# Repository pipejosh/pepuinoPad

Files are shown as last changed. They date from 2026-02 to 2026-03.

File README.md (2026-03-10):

# Pepuino Pad

This is the pepuino pad, a 9 by 9 midi launchpad, with per key rgb illumination (the brightness can only be set to 30% ish) the pepuino pad is a midi compatible launchpad to make music, this project, the shematics and the pcb are made in kicad, and the case and render are made in fusion 360 and it uses the custom made pepuino nano V1 as the main microcontroler (microcontroller based on a rp2040 chip)

###  Shematic
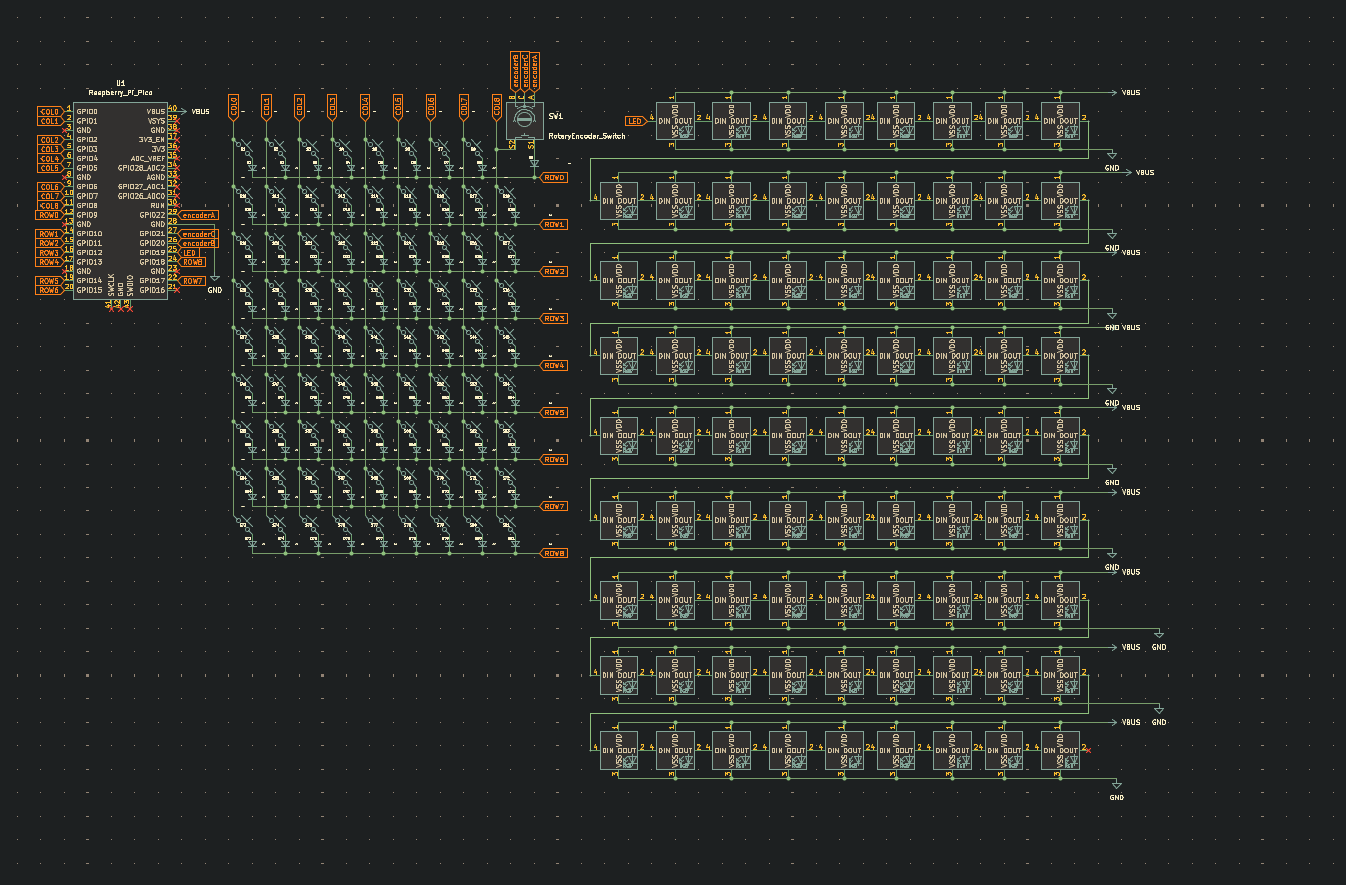
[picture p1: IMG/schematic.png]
schematic
 
### pcb
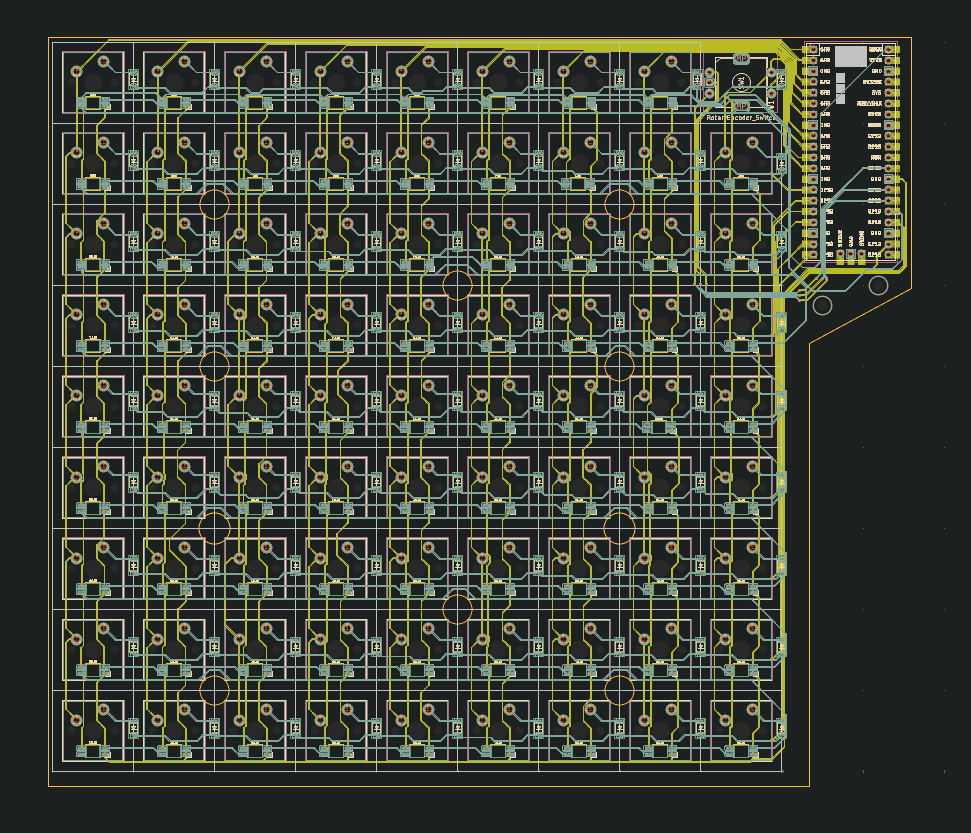
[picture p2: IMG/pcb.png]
pcb
 
### case
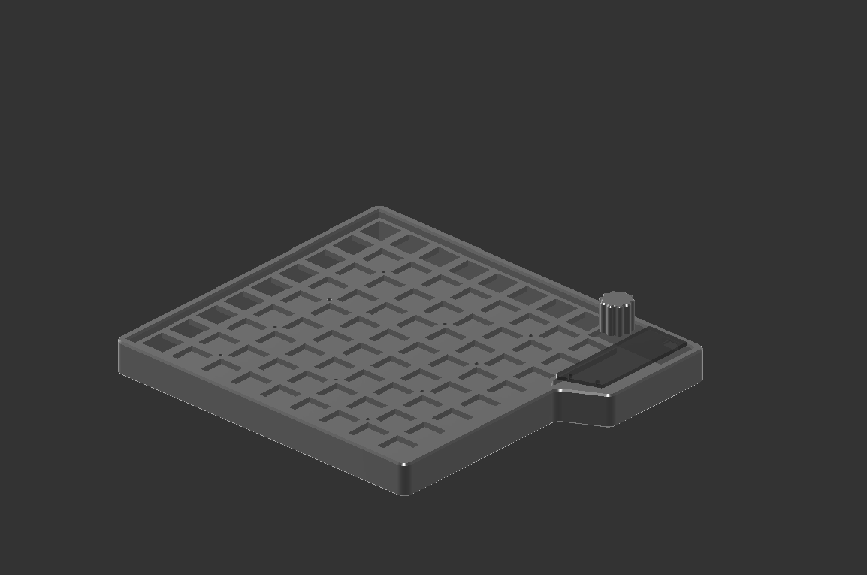
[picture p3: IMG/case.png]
case
 
### render
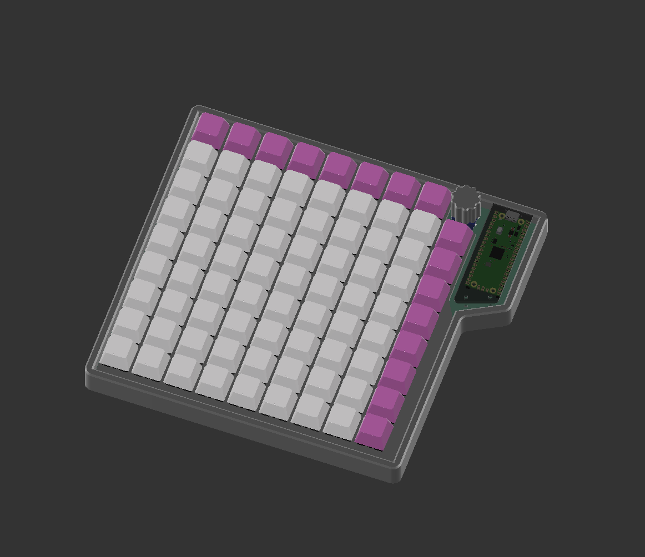
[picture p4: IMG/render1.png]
render1
 
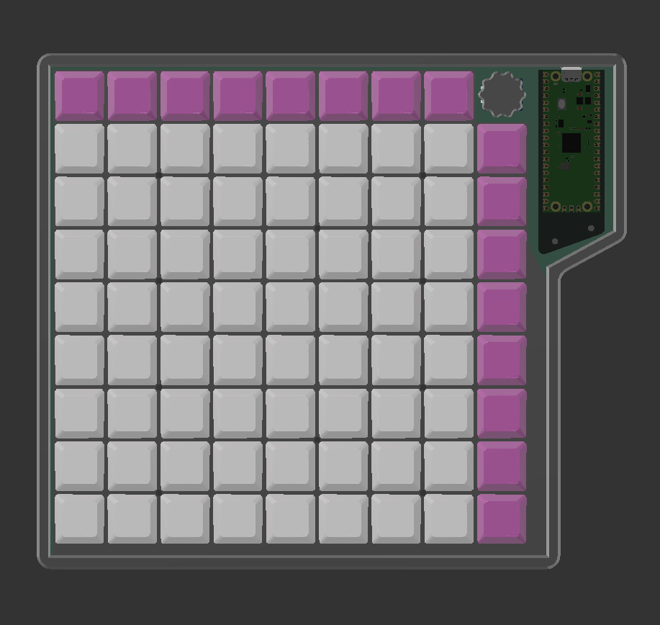
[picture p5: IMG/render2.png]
render2
  

## BOM
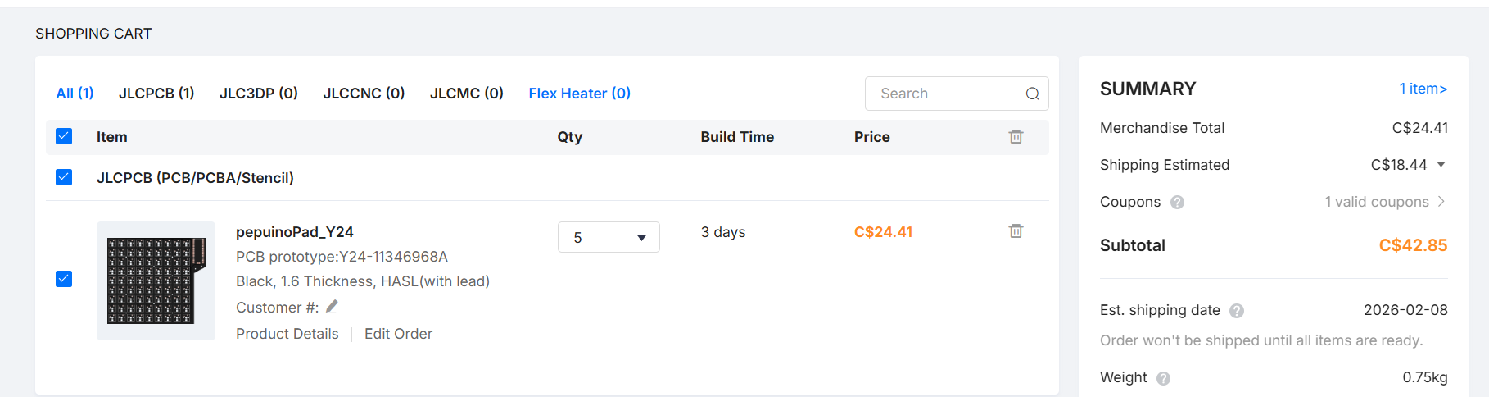
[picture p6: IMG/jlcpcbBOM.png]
BOM
 

## Components (KIT)

| Item | Description | Quantity | Unit Price | Total Price | URL |
|-----|---|---|---|---|-----|
| Blank keycaps | White | 90 | 0,13 | 11,81 | https://www.aliexpress.com/item/32842379355.html |
| Blank keycaps | Green | 20 | 0,19 | 3,77 | https://www.aliexpress.com/item/1005006116865547.html |
| Switches | Mechanical switches | 90 | 0,23 | 20,31 | https://www.aliexpress.com/item/1005009787231480.html |
| Diodes | SMD diodes | 100 | 0,03 | 3,08 | https://www.aliexpress.com/item/1005007160563285.html |
| M2 standoff | M2 standoff 5mm | 50 | 0,05 | 2,47 | https://www.aliexpress.com/item/1005006049595637.html |
| M2 screw | 5mm screw | 50 | 0,03 | 1,65 | https://www.aliexpress.com/item/1005005070119421.html |
| LED | SK6812 | 100 | 0,07 | 6,67 | https://www.aliexpress.com/item/1005005193716172.html |
| Roraty encoder | ec11 | 1 | 1,85 | 1,85 | https://www.aliexpress.com/item/1005007644083514.html |
| Taxes | AliExpress tax | — | — | 4,28 | — |

**Components Subtotal:** **55,89**

---

## PCB

| Item | Description | Price |
|-----|---|---|
| JLCPCB | Pepuino Pad PCB | 24,41 |
| JLCPCB Shipping | PCB shipping + taxes | 18,44 |

---

## Total

| Description | Amount |
|---|---|
| **Grand Total** | **98.74** |

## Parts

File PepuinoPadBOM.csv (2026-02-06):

KIT Items | Description | Quantity | Unit Price | Total Price | URL
blank keycaps | white | 90 | 0,13 | 11,81 | https://www.aliexpress.com/item/32842379355.html?spm=a2g0o.detail.0.0.60810ceR0ceRWl&mp=1
blank keycaps | green | 20 | 0,19 | 3,77 | https://www.aliexpress.com/item/1005006116865547.html?spm=a2g0o.detail.0.0.5325TAR5TAR5dv&mp=1
switches | mechanical switches | 90 | 0,23 | 20,31 | https://www.aliexpress.com/item/1005009787231480.html?spm=a2g0o.detail.0.0.67adNrIhNrIhyD&mp=1
diodes | smd diodes | 100 | 0,03 | 3,08 | https://www.aliexpress.com/item/1005007160563285.html?spm=a2g0o.detail.0.0.7fc4QlPlQlPlQO&mp=1
M2 standoff | M2 standoff 5mm | 50 | 0,05 | 2,47 | https://www.aliexpress.com/item/1005008504707668.html?spm=a2g0o.detail.0.0.5fe4VqYfVqYfAJ&mp=1
M2 screw | 5mm screw | 50 | 0,03 | 1,65 | https://www.aliexpress.com/item/1005005070119421.html
Led | sk6812 | 100 | 0,07 | 6,67 | https://www.aliexpress.com/item/1005005193716172.html?spm=a2g0o.cart.0.0.5b5d38daIIwypf&mp=1
raspberry pico | raspberry pico usb-c | 1 | 3,27 | 3,29 | https://www.aliexpress.com/item/1005006839247100.html?spm=a2g0o.cart.0.0.5b5d38daIIwypf&mp=1
taxes | aliexpress tax |  |  | 4,28
 |  |  | Components | 57,33
CASE Items | Description
JLCPCB | Pepuino Pad PCB | 21,84
JLCPCB Shipping | Shipping for PCB + taxes | 16,87
TOTAL | 96,04

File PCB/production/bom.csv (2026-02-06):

Designator | Footprint | Quantity | Value | LCSC Part #
D1, D10, D11, D12, D13, D14, D15, D16, D17, D18, D19, D2, D20, D21, D22, D23, D24, D25, D26, D27, D28, D29, D3, D30, D31, D32, D33, D34, D35, D36, D37, D38, D39, D4, D40, D41, D42, D43, D44, D45, D46, D47, D48, D49, D5, D50, D51, D52, D53, D54, D55, D56, D57, D58, D59, D6, D60, D61, D62, D63, D64, D65, D66, D67, D68, D69, D7, D70, D71, D72, D73, D74, D75, D76, D77, D78, D79, D8, D80, D81, D9 | Diode_SOD-123 | 81 | ~
D100, D101, D102, D103, D104, D105, D106, D107, D108, D109, D110, D111, D112, D113, D114, D115, D116, D117, D118, D119, D120, D121, D122, D123, D124, D125, D126, D127, D128, D129, D130, D131, D132, D133, D134, D135, D136, D137, D138, D139, D140, D141, D142, D143, D144, D145, D146, D147, D148, D149, D150, D151, D152, D153, D154, D155, D156, D157, D158, D159, D160, D161, D162, D82, D83, D84, D85, D86, D87, D88, D89, D90, D91, D92, D93, D94, D95, D96, D97, D98, D99 | LED_SK6812MINI | 81 | LED_SK6812MINI | C5149201
S1, S10, S11, S12, S13, S14, S15, S16, S17, S18, S19, S2, S20, S21, S22, S23, S24, S25, S26, S27, S28, S29, S3, S30, S31, S32, S33, S34, S35, S36, S37, S38, S39, S4, S40, S41, S42, S43, S44, S45, S46, S47, S48, S49, S5, S50, S51, S52, S53, S54, S55, S56, S57, S58, S59, S6, S60, S61, S62, S63, S64, S65, S66, S67, S68, S69, S7, S70, S71, S72, S73, S74, S75, S76, S77, S78, S79, S8, S80, S81, S9 | MX_PCB_1.00u | 81 | ~
U1 | Raspberry_Pi_Pico | 1 | Raspberry_Pi_Pico

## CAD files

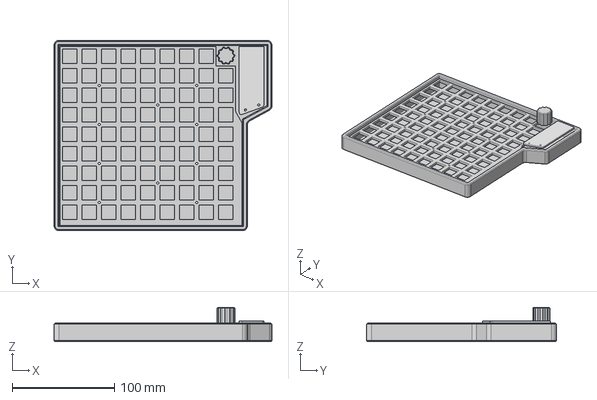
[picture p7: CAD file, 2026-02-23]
CAD/pepuinoPad_case.step
213.0 x 186.0 x 33.5 mm

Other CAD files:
CAD/pepuinoPad.f3z

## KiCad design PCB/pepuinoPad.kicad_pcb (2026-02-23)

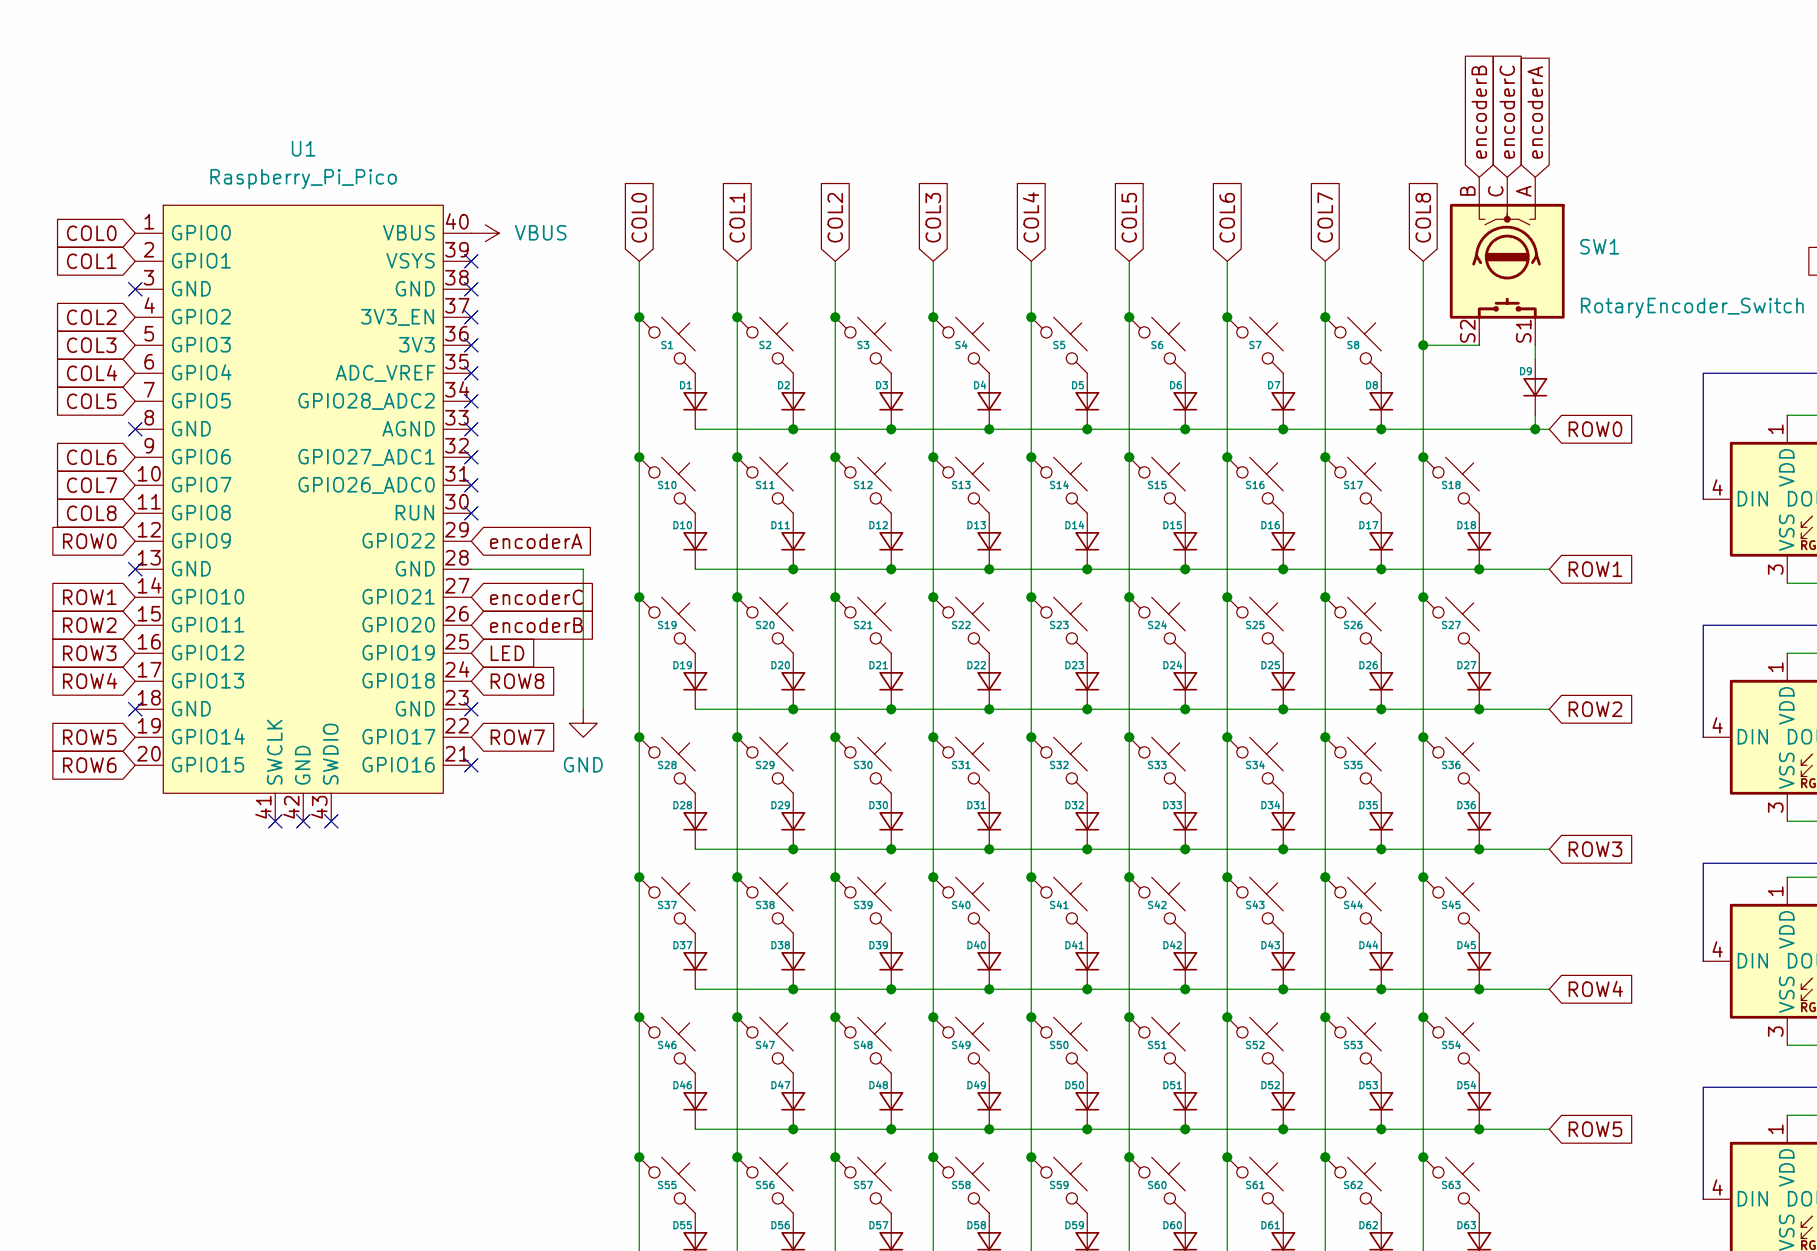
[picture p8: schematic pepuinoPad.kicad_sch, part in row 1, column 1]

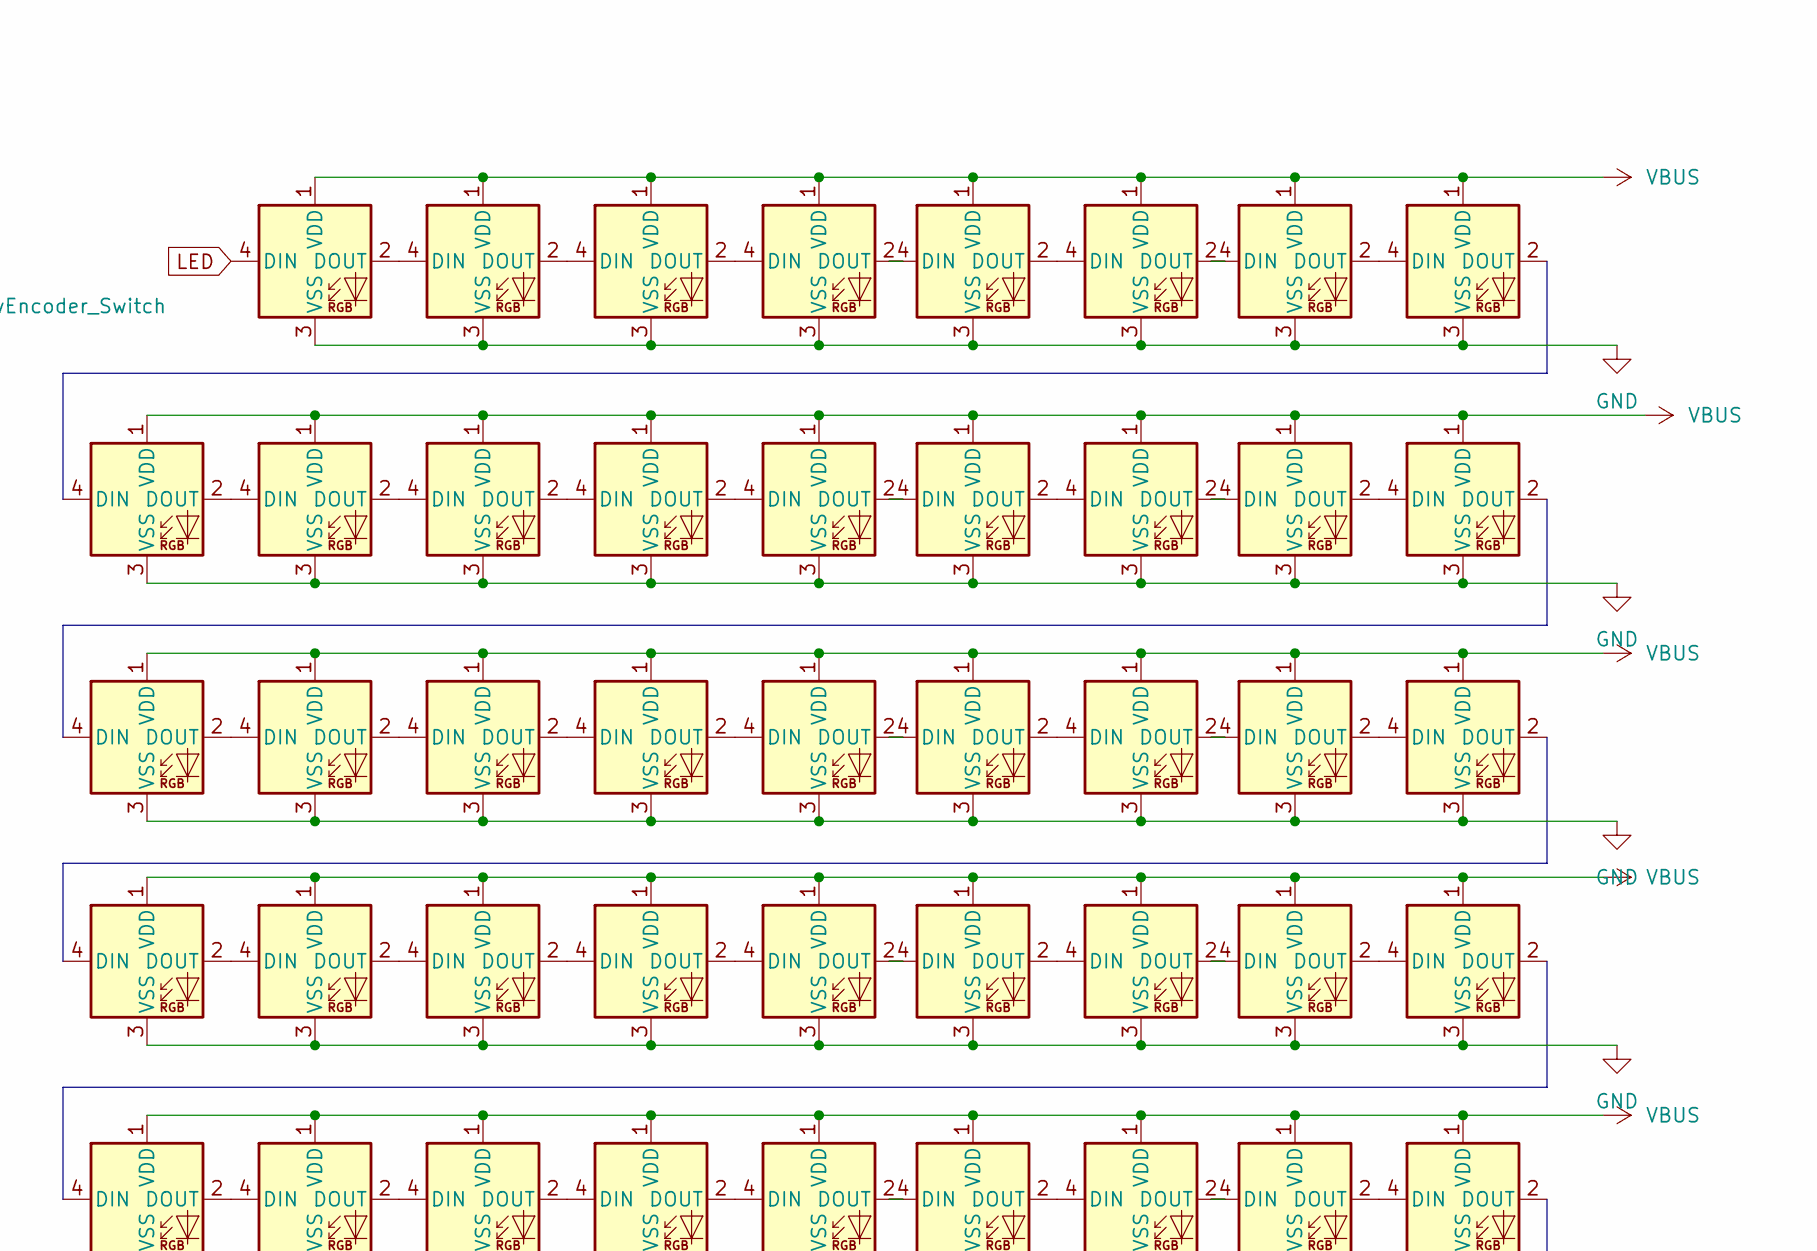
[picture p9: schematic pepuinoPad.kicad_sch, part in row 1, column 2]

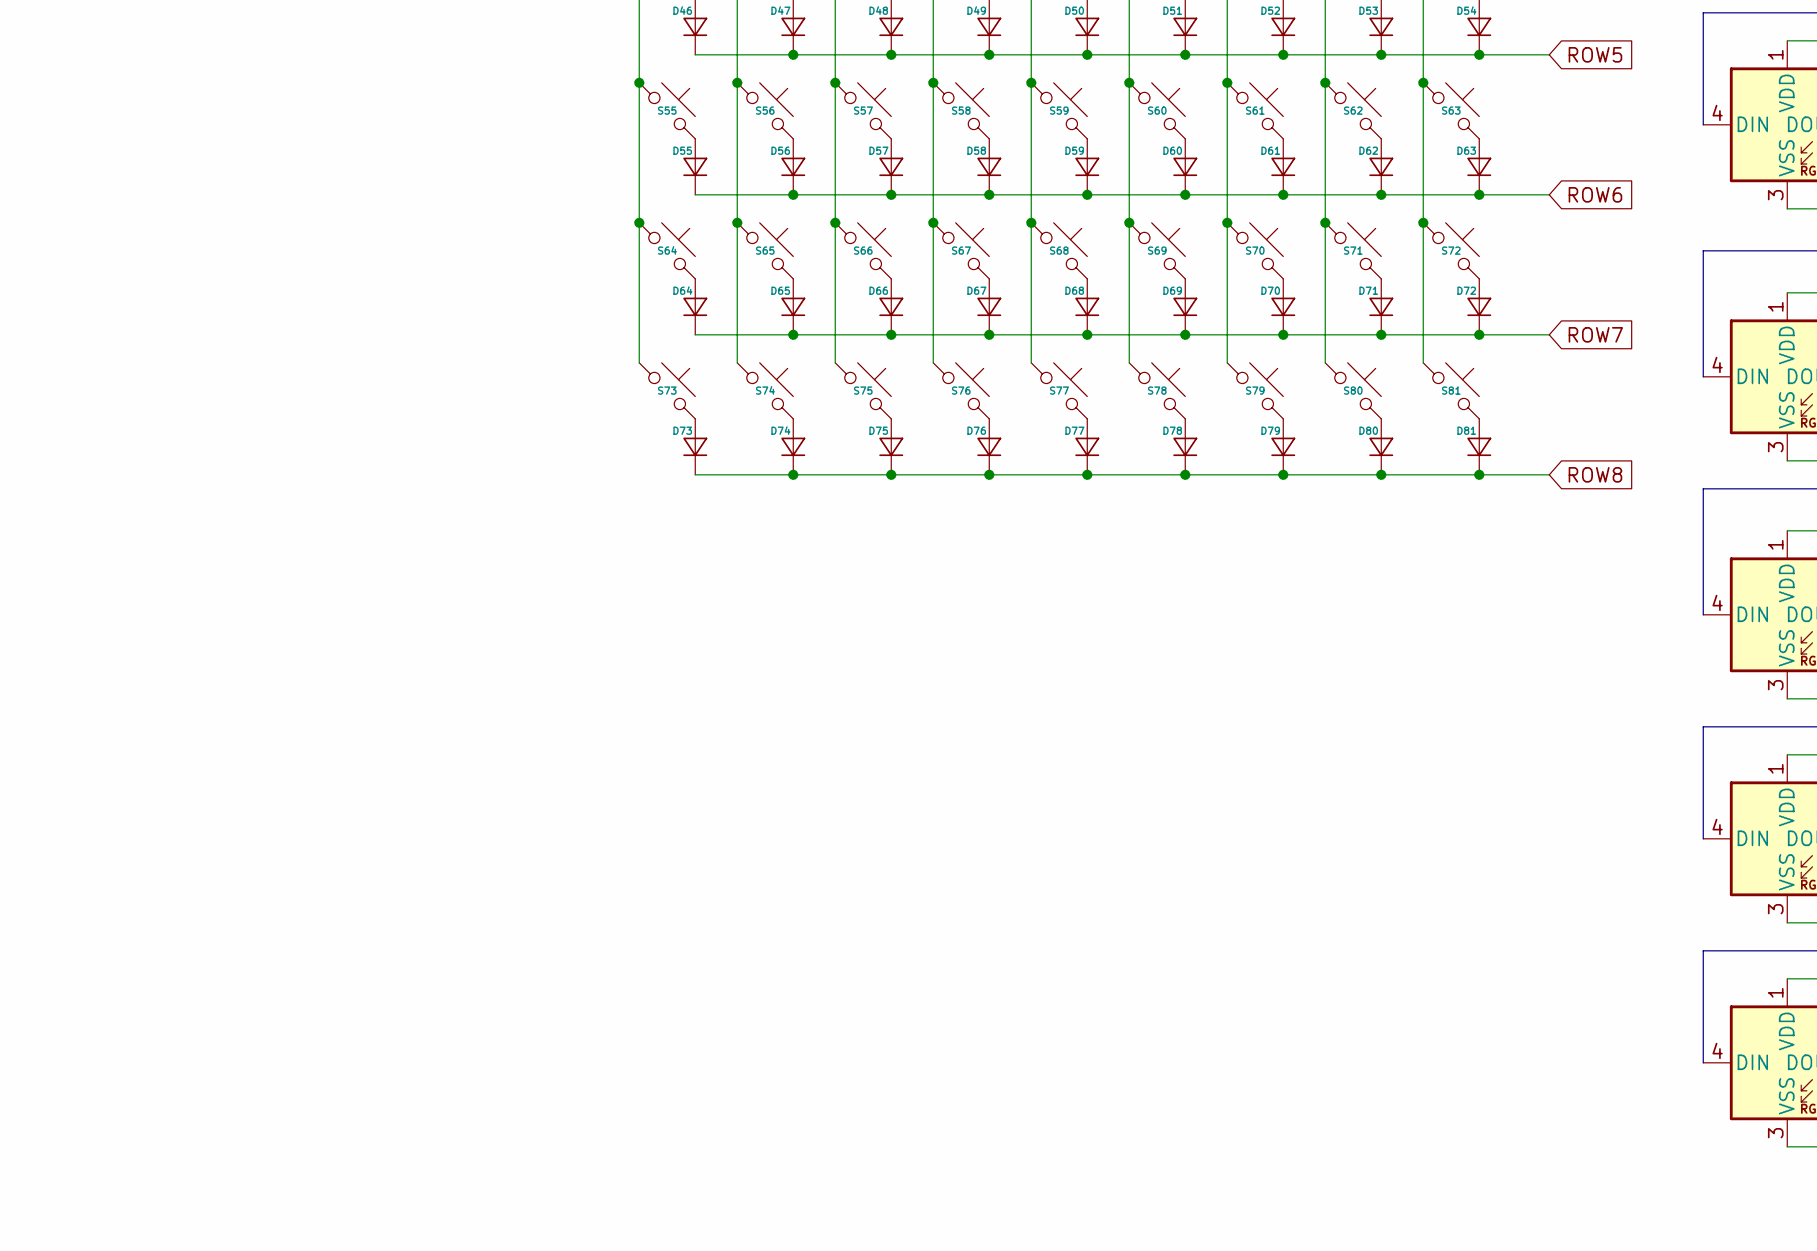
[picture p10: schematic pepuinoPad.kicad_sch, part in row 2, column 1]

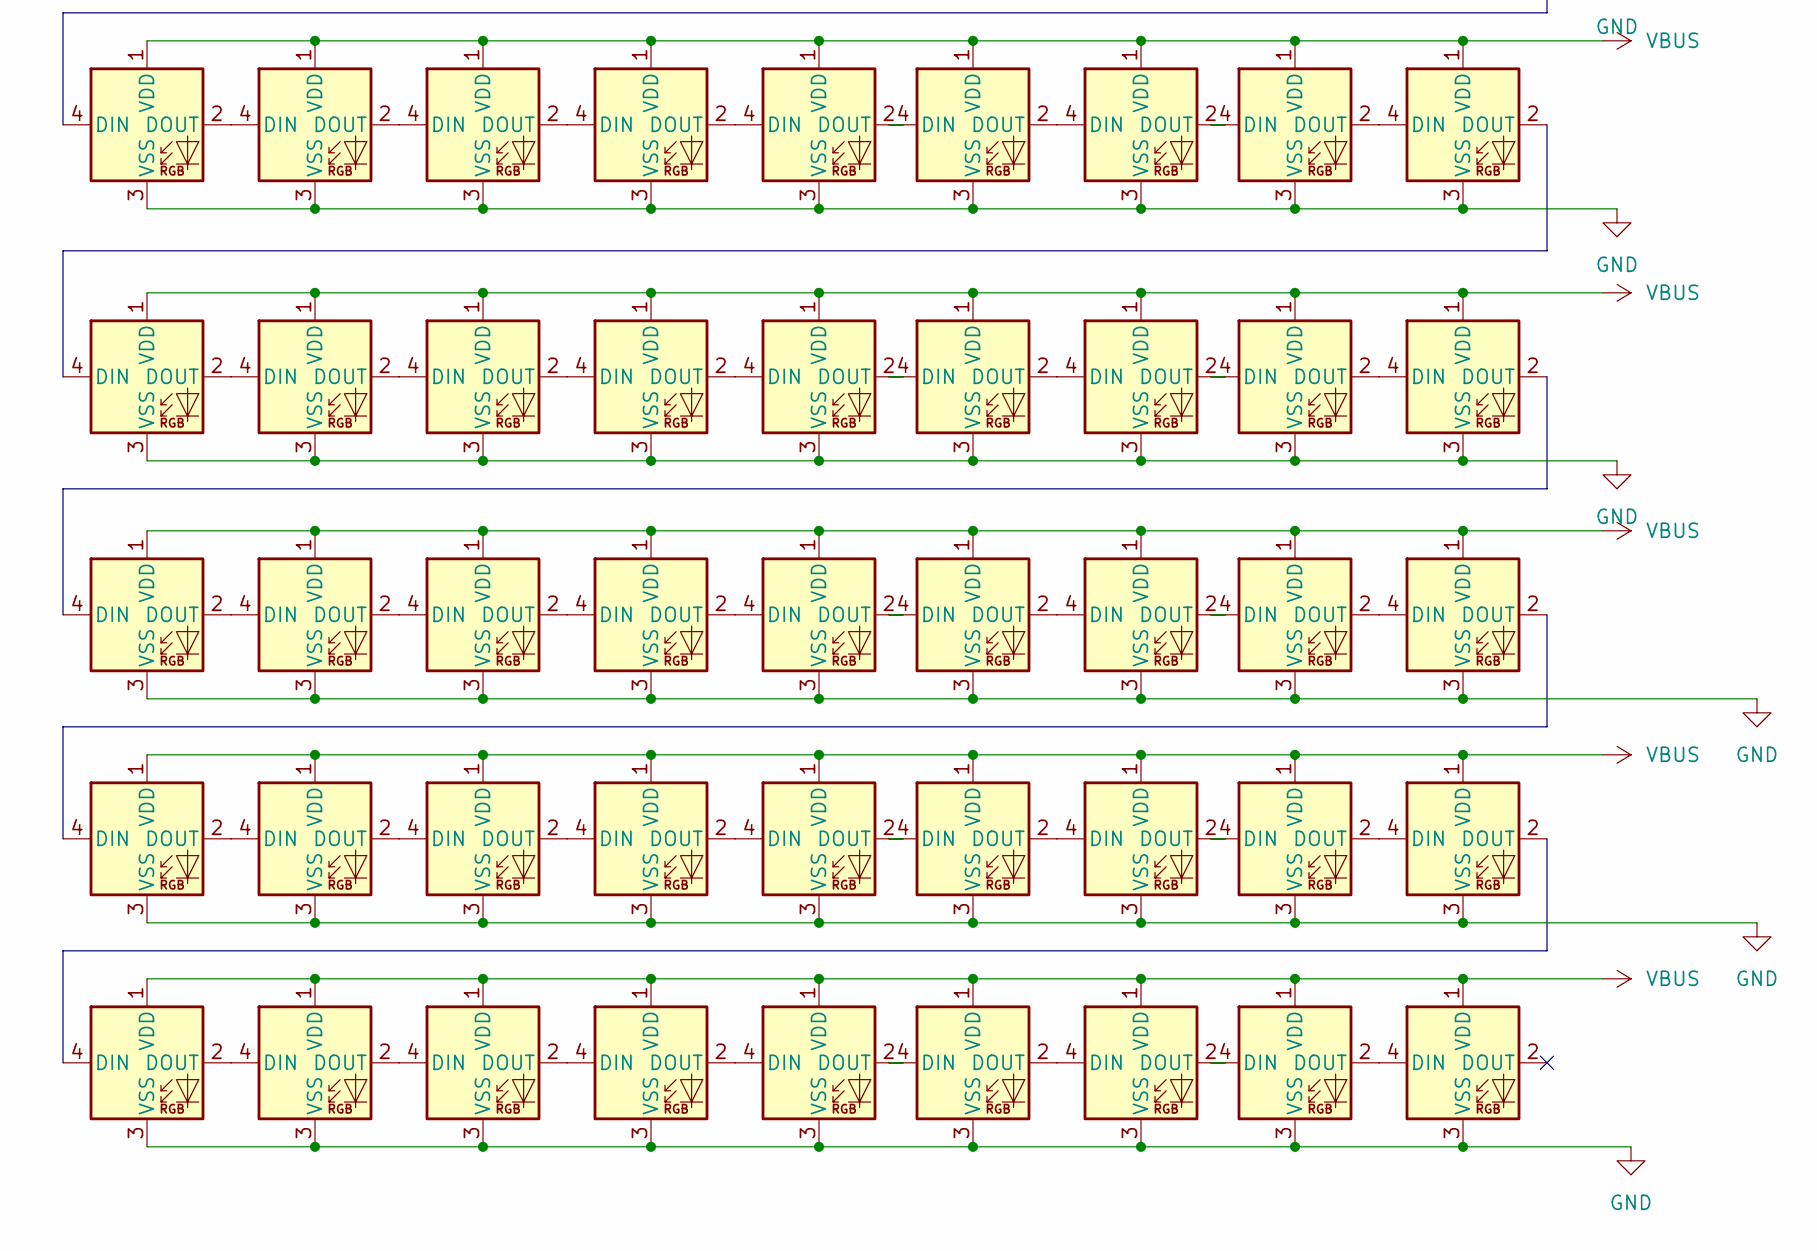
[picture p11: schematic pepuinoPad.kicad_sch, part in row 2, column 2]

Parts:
D1, D2, D3, D4, D5, D6, D7, D8, D9, D10, D11, D12, D13, D14, D15, D16, D17, D18, D19, D20, D21, D22, D23, D24, D25, D26, D27, D28, D29, D30, D31, D32, D33, D34, D35, D36, D37, D38, D39, D40, D41, D42, D43, D44, D45, D46, D47, D48, D49, D50, D51, D52, D53, D54, D55, D56, D57, D58, D59, D60, D61, D62, D63, D64, D65, D66, D67, D68, D69, D70, D71, D72, D73, D74, D75, D76, D77, D78, D79, D80, D81: Diode_SOD-123
D83, D84, D85, D86, D87, D88, D89, D90, D91, D92, D93, D94, D95, D96, D97, D98, D99, D100, D101, D102, D103, D104, D105, D106, D107, D108, D109, D110, D111, D112, D113, D114, D115, D116, D117, D118, D119, D120, D121, D122, D123, D124, D125, D126, D127, D128, D129, D130, D131, D132, D133, D134, D135, D136, D137, D138, D139, D140, D141, D142, D143, D144, D145, D146, D147, D148, D149, D150, D151, D152, D153, D154, D155, D156, D157, D158, D159, D160, D161, D162: LED_SK6812MINI; YS-SK6812MINI-E; LCSC C5149201
S1, S2, S3, S4, S5, S6, S7, S8, S10, S11, S12, S13, S14, S15, S16, S17, S18, S19, S20, S21, S22, S23, S24, S25, S26, S27, S28, S29, S30, S31, S32, S33, S34, S35, S36, S37, S38, S39, S40, S41, S42, S43, S44, S45, S46, S47, S48, S49, S50, S51, S52, S53, S54, S55, S56, S57, S58, S59, S60, S61, S62, S63, S64, S65, S66, S67, S68, S69, S70, S71, S72, S73, S74, S75, S76, S77, S78, S79, S80, S81: MX_PCB_1.00u
SW1: RotaryEncoder_Switch; ROT_Alps_EC11E-Switch
U1: Raspberry_Pi_Pico

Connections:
COL0: S1.1, S10.1, S19.1, S28.1, S37.1, S46.1, S55.1, S64.1, S73.1, U1.1 (GPIO0)
COL1: S2.1, S11.1, S20.1, S29.1, S38.1, S47.1, S56.1, S65.1, S74.1, U1.2 (GPIO1)
COL2: S3.1, S12.1, S21.1, S30.1, S39.1, S48.1, S57.1, S66.1, S75.1, U1.4 (GPIO2)
COL3: S4.1, S13.1, S22.1, S31.1, S40.1, S49.1, S58.1, S67.1, S76.1, U1.5 (GPIO3)
COL4: S5.1, S14.1, S23.1, S32.1, S41.1, S50.1, S59.1, S68.1, S77.1, U1.6 (GPIO4)
COL5: S6.1, S15.1, S24.1, S33.1, S42.1, S51.1, S60.1, S69.1, S78.1, U1.7 (GPIO5)
COL6: S7.1, S16.1, S25.1, S34.1, S43.1, S52.1, S61.1, S70.1, S79.1, U1.9 (GPIO6)
COL7: S8.1, S17.1, S26.1, S35.1, S44.1, S53.1, S62.1, S71.1, S80.1, U1.10 (GPIO7)
COL8: S18.1, S27.1, S36.1, S45.1, S54.1, S63.1, S72.1, S81.1, SW1.S2, U1.11 (GPIO8)
GND: D83.3 (VSS), D84.3 (VSS), D85.3 (VSS), D86.3 (VSS), D87.3 (VSS), D88.3 (VSS), D89.3 (VSS), D90.3 (VSS), D91.3 (VSS), D92.3 (VSS), D93.3 (VSS), D94.3 (VSS), D95.3 (VSS), D96.3 (VSS), D97.3 (VSS), D98.3 (VSS), D99.3 (VSS), D100.3 (VSS), D101.3 (VSS), D102.3 (VSS), D103.3 (VSS), D104.3 (VSS), D105.3 (VSS), D106.3 (VSS), D107.3 (VSS), D108.3 (VSS), D109.3 (VSS), D110.3 (VSS), D111.3 (VSS), D112.3 (VSS), D113.3 (VSS), D114.3 (VSS), D115.3 (VSS), D116.3 (VSS), D117.3 (VSS), D118.3 (VSS), D119.3 (VSS), D120.3 (VSS), D121.3 (VSS), D122.3 (VSS), D123.3 (VSS), D124.3 (VSS), D125.3 (VSS), D126.3 (VSS), D127.3 (VSS), D128.3 (VSS), D129.3 (VSS), D130.3 (VSS), D131.3 (VSS), D132.3 (VSS), D133.3 (VSS), D134.3 (VSS), D135.3 (VSS), D136.3 (VSS), D137.3 (VSS), D138.3 (VSS), D139.3 (VSS), D140.3 (VSS), D141.3 (VSS), D142.3 (VSS), D143.3 (VSS), D144.3 (VSS), D145.3 (VSS), D146.3 (VSS), D147.3 (VSS), D148.3 (VSS), D149.3 (VSS), D150.3 (VSS), D151.3 (VSS), D152.3 (VSS), D153.3 (VSS), D154.3 (VSS), D155.3 (VSS), D156.3 (VSS), D157.3 (VSS), D158.3 (VSS), D159.3 (VSS), D160.3 (VSS), D161.3 (VSS), D162.3 (VSS), U1.28 (GND)
LED: D83.4 (DIN), U1.25 (GPIO19)
unnamed: D1.2 (A), S1.2
unnamed: D2.2 (A), S2.2
unnamed: D3.2 (A), S3.2
unnamed: D4.2 (A), S4.2
unnamed: D5.2 (A), S5.2
unnamed: D6.2 (A), S6.2
unnamed: D7.2 (A), S7.2
unnamed: D8.2 (A), S8.2
unnamed: D9.2 (A), SW1.S1
unnamed: D10.2 (A), S10.2
unnamed: D11.2 (A), S11.2
unnamed: D12.2 (A), S12.2
unnamed: D13.2 (A), S13.2
unnamed: D14.2 (A), S14.2
unnamed: D15.2 (A), S15.2
unnamed: D16.2 (A), S16.2
unnamed: D17.2 (A), S17.2
unnamed: D18.2 (A), S18.2
unnamed: D19.2 (A), S19.2
unnamed: D20.2 (A), S20.2
unnamed: D21.2 (A), S21.2
unnamed: D22.2 (A), S22.2
unnamed: D23.2 (A), S23.2
unnamed: D24.2 (A), S24.2
unnamed: D25.2 (A), S25.2
unnamed: D26.2 (A), S26.2
unnamed: D27.2 (A), S27.2
unnamed: D28.2 (A), S28.2
unnamed: D29.2 (A), S29.2
unnamed: D30.2 (A), S30.2
unnamed: D31.2 (A), S31.2
unnamed: D32.2 (A), S32.2
unnamed: D33.2 (A), S33.2
unnamed: D34.2 (A), S34.2
unnamed: D35.2 (A), S35.2
unnamed: D36.2 (A), S36.2
unnamed: D37.2 (A), S37.2
unnamed: D38.2 (A), S38.2
unnamed: D39.2 (A), S39.2
unnamed: D40.2 (A), S40.2
unnamed: D41.2 (A), S41.2
unnamed: D42.2 (A), S42.2
unnamed: D43.2 (A), S43.2
unnamed: D44.2 (A), S44.2
unnamed: D45.2 (A), S45.2
unnamed: D46.2 (A), S46.2
unnamed: D47.2 (A), S47.2
unnamed: D48.2 (A), S48.2
unnamed: D49.2 (A), S49.2
unnamed: D50.2 (A), S50.2
unnamed: D51.2 (A), S51.2
unnamed: D52.2 (A), S52.2
unnamed: D53.2 (A), S53.2
unnamed: D54.2 (A), S54.2
unnamed: D55.2 (A), S55.2
unnamed: D56.2 (A), S56.2
unnamed: D57.2 (A), S57.2
unnamed: D58.2 (A), S58.2
unnamed: D59.2 (A), S59.2
unnamed: D60.2 (A), S60.2
unnamed: D61.2 (A), S61.2
unnamed: D62.2 (A), S62.2
unnamed: D63.2 (A), S63.2
unnamed: D64.2 (A), S64.2
unnamed: D65.2 (A), S65.2
unnamed: D66.2 (A), S66.2
unnamed: D67.2 (A), S67.2
unnamed: D68.2 (A), S68.2
unnamed: D69.2 (A), S69.2
unnamed: D70.2 (A), S70.2
unnamed: D71.2 (A), S71.2
unnamed: D72.2 (A), S72.2
unnamed: D73.2 (A), S73.2
unnamed: D74.2 (A), S74.2
unnamed: D75.2 (A), S75.2
unnamed: D76.2 (A), S76.2
unnamed: D77.2 (A), S77.2
unnamed: D78.2 (A), S78.2
unnamed: D79.2 (A), S79.2
unnamed: D80.2 (A), S80.2
unnamed: D81.2 (A), S81.2
unnamed: D83.2 (DOUT), D84.4 (DIN)
unnamed: D84.2 (DOUT), D85.4 (DIN)
unnamed: D85.2 (DOUT), D86.4 (DIN)
unnamed: D86.2 (DOUT), D87.4 (DIN)
unnamed: D87.2 (DOUT), D88.4 (DIN)
unnamed: D88.2 (DOUT), D89.4 (DIN)
unnamed: D89.2 (DOUT), D90.4 (DIN)
unnamed: D90.2 (DOUT), D91.4 (DIN)
unnamed: D91.2 (DOUT), D92.4 (DIN)
unnamed: D92.2 (DOUT), D93.4 (DIN)
unnamed: D93.2 (DOUT), D94.4 (DIN)
unnamed: D94.2 (DOUT), D95.4 (DIN)
unnamed: D95.2 (DOUT), D96.4 (DIN)
unnamed: D96.2 (DOUT), D97.4 (DIN)
unnamed: D97.2 (DOUT), D98.4 (DIN)
unnamed: D98.2 (DOUT), D99.4 (DIN)
unnamed: D99.2 (DOUT), D100.4 (DIN)
unnamed: D100.2 (DOUT), D101.4 (DIN)
unnamed: D101.2 (DOUT), D102.4 (DIN)
unnamed: D102.2 (DOUT), D103.4 (DIN)
unnamed: D103.2 (DOUT), D104.4 (DIN)
unnamed: D104.2 (DOUT), D105.4 (DIN)
unnamed: D105.2 (DOUT), D106.4 (DIN)
unnamed: D106.2 (DOUT), D107.4 (DIN)
unnamed: D107.2 (DOUT), D108.4 (DIN)
unnamed: D108.2 (DOUT), D109.4 (DIN)
unnamed: D109.2 (DOUT), D110.4 (DIN)
unnamed: D110.2 (DOUT), D111.4 (DIN)
unnamed: D111.2 (DOUT), D112.4 (DIN)
unnamed: D112.2 (DOUT), D113.4 (DIN)
unnamed: D113.2 (DOUT), D114.4 (DIN)
unnamed: D114.2 (DOUT), D115.4 (DIN)
unnamed: D115.2 (DOUT), D116.4 (DIN)
unnamed: D116.2 (DOUT), D117.4 (DIN)
unnamed: D117.2 (DOUT), D118.4 (DIN)
unnamed: D118.2 (DOUT), D119.4 (DIN)
unnamed: D119.2 (DOUT), D120.4 (DIN)
unnamed: D120.2 (DOUT), D121.4 (DIN)
unnamed: D121.2 (DOUT), D122.4 (DIN)
unnamed: D122.2 (DOUT), D123.4 (DIN)
unnamed: D123.2 (DOUT), D124.4 (DIN)
unnamed: D124.2 (DOUT), D125.4 (DIN)
unnamed: D125.2 (DOUT), D126.4 (DIN)
unnamed: D126.2 (DOUT), D127.4 (DIN)
unnamed: D127.2 (DOUT), D128.4 (DIN)
unnamed: D128.2 (DOUT), D129.4 (DIN)
unnamed: D129.2 (DOUT), D130.4 (DIN)
unnamed: D130.2 (DOUT), D131.4 (DIN)
unnamed: D131.2 (DOUT), D132.4 (DIN)
unnamed: D132.2 (DOUT), D133.4 (DIN)
unnamed: D133.2 (DOUT), D134.4 (DIN)
unnamed: D134.2 (DOUT), D135.4 (DIN)
unnamed: D135.2 (DOUT), D136.4 (DIN)
unnamed: D136.2 (DOUT), D137.4 (DIN)
unnamed: D137.2 (DOUT), D138.4 (DIN)
unnamed: D138.2 (DOUT), D139.4 (DIN)
unnamed: D139.2 (DOUT), D140.4 (DIN)
unnamed: D140.2 (DOUT), D141.4 (DIN)
unnamed: D141.2 (DOUT), D142.4 (DIN)
unnamed: D142.2 (DOUT), D143.4 (DIN)
unnamed: D143.2 (DOUT), D144.4 (DIN)
unnamed: D144.2 (DOUT), D145.4 (DIN)
unnamed: D145.2 (DOUT), D146.4 (DIN)
unnamed: D146.2 (DOUT), D147.4 (DIN)
unnamed: D147.2 (DOUT), D148.4 (DIN)
unnamed: D148.2 (DOUT), D149.4 (DIN)
unnamed: D149.2 (DOUT), D150.4 (DIN)
unnamed: D150.2 (DOUT), D151.4 (DIN)
unnamed: D151.2 (DOUT), D152.4 (DIN)
unnamed: D152.2 (DOUT), D153.4 (DIN)
unnamed: D153.2 (DOUT), D154.4 (DIN)
unnamed: D154.2 (DOUT), D155.4 (DIN)
unnamed: D155.2 (DOUT), D156.4 (DIN)
unnamed: D156.2 (DOUT), D157.4 (DIN)
unnamed: D157.2 (DOUT), D158.4 (DIN)
unnamed: D158.2 (DOUT), D159.4 (DIN)
unnamed: D159.2 (DOUT), D160.4 (DIN)
unnamed: D160.2 (DOUT), D161.4 (DIN)
unnamed: D161.2 (DOUT), D162.4 (DIN)
ROW0: D1.1 (K), D2.1 (K), D3.1 (K), D4.1 (K), D5.1 (K), D6.1 (K), D7.1 (K), D8.1 (K), D9.1 (K), U1.12 (GPIO9)
ROW1: D10.1 (K), D11.1 (K), D12.1 (K), D13.1 (K), D14.1 (K), D15.1 (K), D16.1 (K), D17.1 (K), D18.1 (K), U1.14 (GPIO10)
ROW2: D19.1 (K), D20.1 (K), D21.1 (K), D22.1 (K), D23.1 (K), D24.1 (K), D25.1 (K), D26.1 (K), D27.1 (K), U1.15 (GPIO11)
ROW3: D28.1 (K), D29.1 (K), D30.1 (K), D31.1 (K), D32.1 (K), D33.1 (K), D34.1 (K), D35.1 (K), D36.1 (K), U1.16 (GPIO12)
ROW4: D37.1 (K), D38.1 (K), D39.1 (K), D40.1 (K), D41.1 (K), D42.1 (K), D43.1 (K), D44.1 (K), D45.1 (K), U1.17 (GPIO13)
ROW5: D46.1 (K), D47.1 (K), D48.1 (K), D49.1 (K), D50.1 (K), D51.1 (K), D52.1 (K), D53.1 (K), D54.1 (K), U1.19 (GPIO14)
ROW6: D55.1 (K), D56.1 (K), D57.1 (K), D58.1 (K), D59.1 (K), D60.1 (K), D61.1 (K), D62.1 (K), D63.1 (K), U1.20 (GPIO15)
ROW7: D64.1 (K), D65.1 (K), D66.1 (K), D67.1 (K), D68.1 (K), D69.1 (K), D70.1 (K), D71.1 (K), D72.1 (K), U1.22 (GPIO17)
ROW8: D73.1 (K), D74.1 (K), D75.1 (K), D76.1 (K), D77.1 (K), D78.1 (K), D79.1 (K), D80.1 (K), D81.1 (K), U1.24 (GPIO18)
VBUS: D83.1 (VDD), D84.1 (VDD), D85.1 (VDD), D86.1 (VDD), D87.1 (VDD), D88.1 (VDD), D89.1 (VDD), D90.1 (VDD), D91.1 (VDD), D92.1 (VDD), D93.1 (VDD), D94.1 (VDD), D95.1 (VDD), D96.1 (VDD), D97.1 (VDD), D98.1 (VDD), D99.1 (VDD), D100.1 (VDD), D101.1 (VDD), D102.1 (VDD), D103.1 (VDD), D104.1 (VDD), D105.1 (VDD), D106.1 (VDD), D107.1 (VDD), D108.1 (VDD), D109.1 (VDD), D110.1 (VDD), D111.1 (VDD), D112.1 (VDD), D113.1 (VDD), D114.1 (VDD), D115.1 (VDD), D116.1 (VDD), D117.1 (VDD), D118.1 (VDD), D119.1 (VDD), D120.1 (VDD), D121.1 (VDD), D122.1 (VDD), D123.1 (VDD), D124.1 (VDD), D125.1 (VDD), D126.1 (VDD), D127.1 (VDD), D128.1 (VDD), D129.1 (VDD), D130.1 (VDD), D131.1 (VDD), D132.1 (VDD), D133.1 (VDD), D134.1 (VDD), D135.1 (VDD), D136.1 (VDD), D137.1 (VDD), D138.1 (VDD), D139.1 (VDD), D140.1 (VDD), D141.1 (VDD), D142.1 (VDD), D143.1 (VDD), D144.1 (VDD), D145.1 (VDD), D146.1 (VDD), D147.1 (VDD), D148.1 (VDD), D149.1 (VDD), D150.1 (VDD), D151.1 (VDD), D152.1 (VDD), D153.1 (VDD), D154.1 (VDD), D155.1 (VDD), D156.1 (VDD), D157.1 (VDD), D158.1 (VDD), D159.1 (VDD), D160.1 (VDD), D161.1 (VDD), D162.1 (VDD), U1.40 (VBUS)
encoderA: SW1.A, U1.29 (GPIO22)
encoderB: SW1.B, U1.26 (GPIO20)
encoderC: SW1.C, U1.27 (GPIO21)

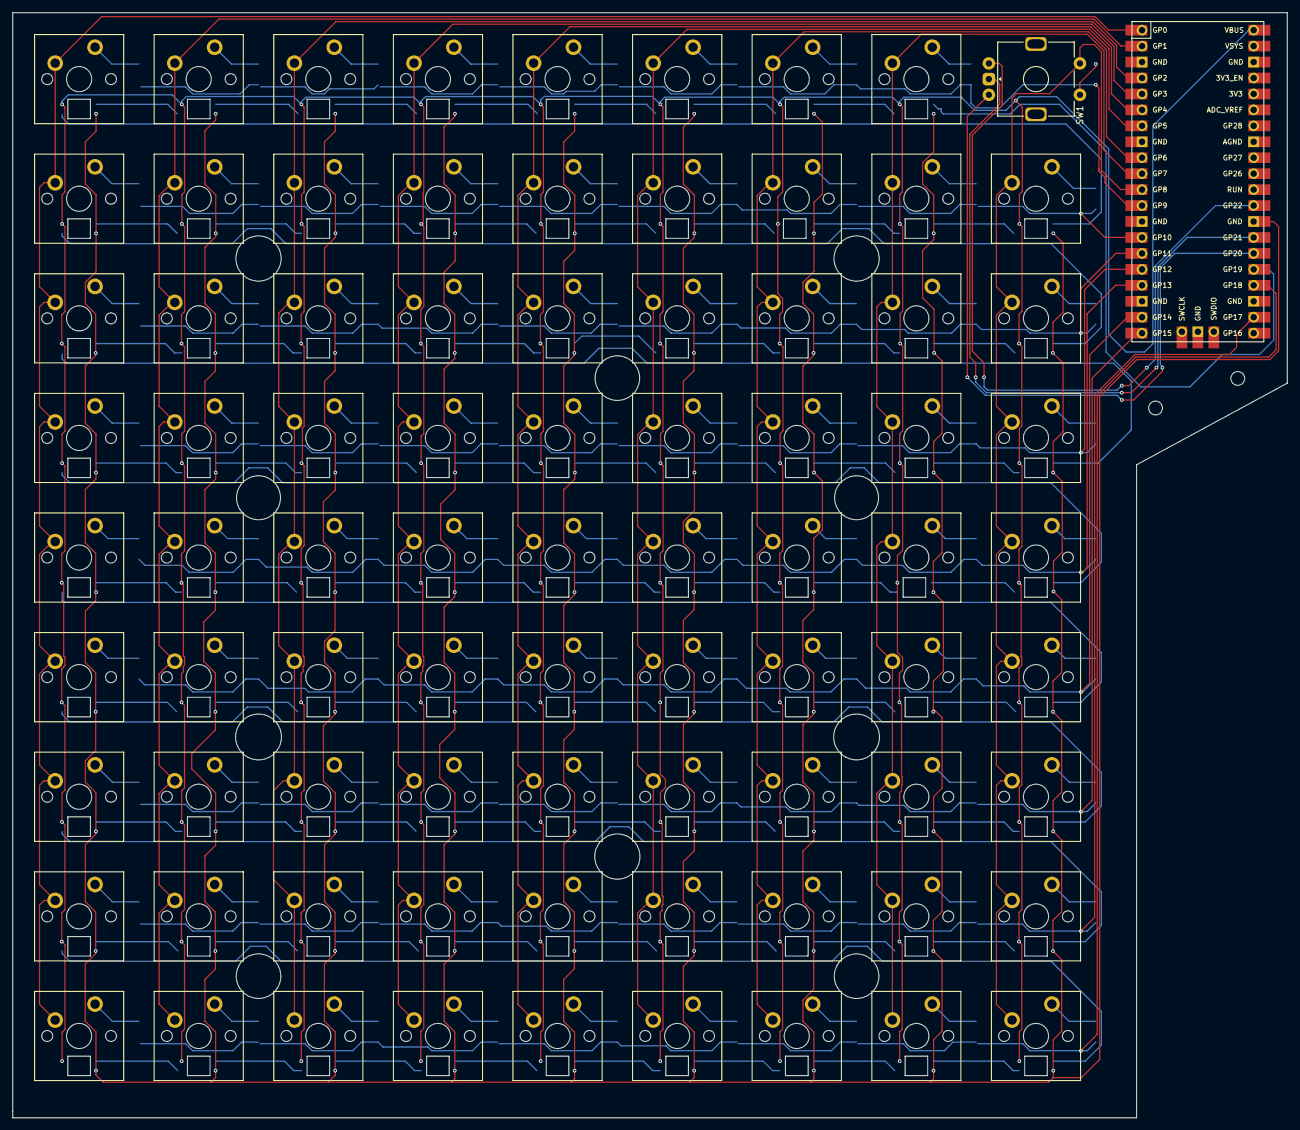
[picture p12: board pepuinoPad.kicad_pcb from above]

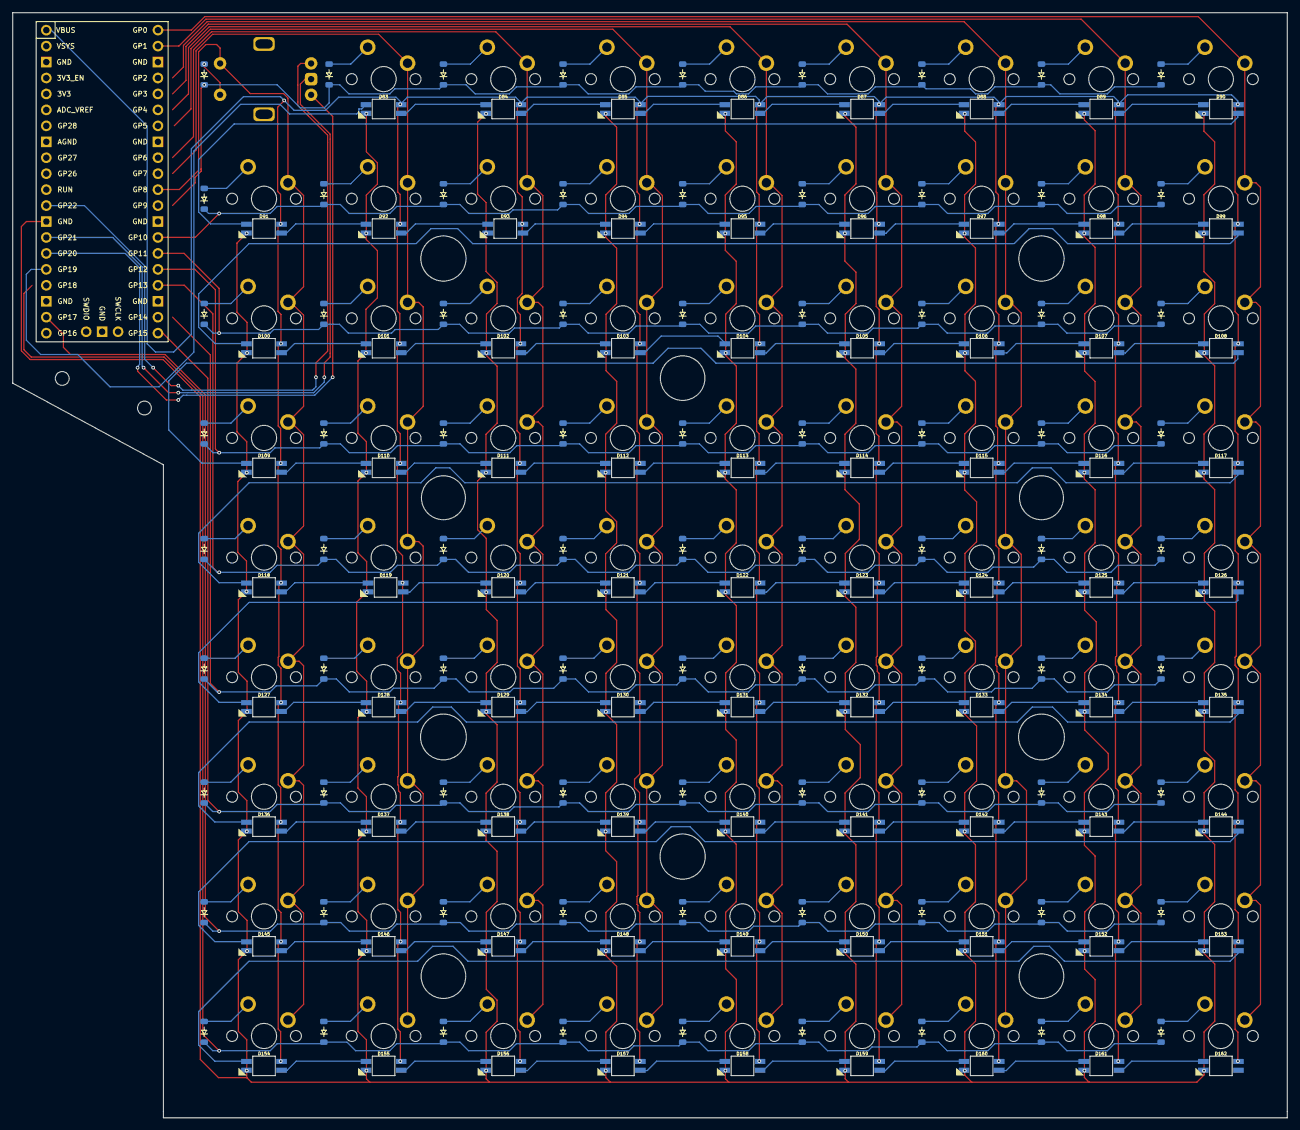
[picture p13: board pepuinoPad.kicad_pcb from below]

Board: 2 copper layers, 203.0 x 176.0 mm, 245 parts (161 on the bottom side), 184 nets.

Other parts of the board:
H11, H12: MountingHole; MountingHole_2.2mm_M2

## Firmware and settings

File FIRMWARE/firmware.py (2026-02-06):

import time
import board
import digitalio
import neopixel
import usb_midi
import adafruit_midi
from adafruit_midi.note_on import NoteOn
from adafruit_midi.note_off import NoteOff

ROWS = 9
COLS = 9
LED_COUNT = 81

ROW_PINS = [
    board.GP2, board.GP3, board.GP4,
    board.GP5, board.GP6, board.GP7,
    board.GP8, board.GP9, board.GP10
]

COL_PINS = [
    board.GP11, board.GP12, board.GP13,
    board.GP14, board.GP15, board.GP16,
    board.GP17, board.GP18, board.GP19
]

LED_PIN = board.GP20
MIDI_CHANNEL = 0
BASE_NOTE = 36      # C2
BRIGHTNESS = 0.25

# MIDI
midi = adafruit_midi.MIDI(
    midi_out=usb_midi.ports[1],
    out_channel=MIDI_CHANNEL
)

# LEDs
pixels = neopixel.NeoPixel(
    LED_PIN,
    LED_COUNT,
    brightness=BRIGHTNESS,
    auto_write=False
)

# Matrix IO
rows = []
cols = []

for pin in ROW_PINS:
    io = digitalio.DigitalInOut(pin)
    io.direction = digitalio.Direction.OUTPUT
    io.value = False
    rows.append(io)

for pin in COL_PINS:
    io = digitalio.DigitalInOut(pin)
    io.direction = digitalio.Direction.INPUT
    io.pull = digitalio.Pull.DOWN
    cols.append(io)

# Key states
state = [[False for _ in range(COLS)] for _ in range(ROWS)]
last_state = [[False for _ in range(COLS)] for _ in range(ROWS)]

def key_index(r, c):
    return r * COLS + c

def is_action_key(r, c):
    return r == 0 or c == COLS - 1

def midi_note(r, c):
    return BASE_NOTE + (r * COLS + c)

def set_led(index, on):
    if on:
        pixels[index] = (0, 80, 255)   # blue
    else:
        pixels[index] = (0, 0, 0)

while True:
    for r in range(ROWS):
        rows[r].value = True
        time.sleep(0.0005)

        for c in range(COLS):
            state[r][c] = cols[c].value

            if state[r][c] != last_state[r][c]:
                idx = key_index(r, c)

                # LED feedback
                set_led(idx, state[r][c])
                pixels.show()

                # MIDI only for non-action keys
                if not is_action_key(r, c):
                    note = midi_note(r, c)
                    if state[r][c]:
                        midi.send(NoteOn(note, 100))
                    else:
                        midi.send(NoteOff(note, 0))

                last_state[r][c] = state[r][c]

        rows[r].value = False

    time.sleep(0.002)

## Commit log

2026-02-06 update pictes / case / pcb / BOM
    [PepuinoPadBOM.csv, bom.csv, designators.csv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]
2026-02-23 add roatry encododer + pepuino nano + update readme and img
    [freerouting.dsn, pepuinoPad.f3z, pepuinoPad.kicad_pcb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]
2026-03-10 Fix Roraty encoder quantity and update subtotal
    Corrected quantity for Roraty encoder and updated subtotal.
2026-03-10 Update M2 standoff link in README.md
